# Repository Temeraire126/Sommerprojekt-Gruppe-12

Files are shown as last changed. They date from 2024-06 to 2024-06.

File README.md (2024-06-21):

KeySync

Ein Softskills-Projekt der Carl von Ossietzky Universität Oldenburg.

Wir haben im Rahmen des Moduls "Softskills und Technische Kompetenzen" einen smarten Schlüsselkassten entwickelt, der die Vermietung von Räumen vereinfachen soll.

Wichtig: Dies ist ein Prototyp und sollte auf keinen Fall in seiner jetztigen Form tatsächlich verwendet werden.

Das Projekt besteht aus zwei Komponenten, einem Mainboard/Hub und einer beliebigen Anzahl an Schlüsselkästen. 
Auf dem Mainboard werden auf Anfrage Zahlencodes generiert, die dann am entsprechenden Schlüsselkasten eingegeben werden können um den Schlüssel freizugeben.

Betrieben wird das System von mehreren ESP8266 und nutzt das ESPnow protocoll zur Komunikation. Die Gehäuse wurden mit einem Lasercutter hergestellt.

Die Nutzung ist simpel genug:
  1. Ein Raum wird bei einer Person (z.B. Raumverwaltung oder Rezeption) angefordert.
  2. Durch Knopfdruck am Mainboard wird ein 4 stelliger Pin generiert und kann an die ensprechende Person weiter geleitet werden.
  3. Bei eingabe des Pins öffnet sich der Deckel und der Schlüssel kann entnommen werden
  4. Wenn der richtige Schlüssel wieder in den Kassten gelegt wird schließt sich der Deckel automatisch.

     Sowohl auf dem Mainbard, als auch auf dem Schlüsselkasten wird der Raumstatus mittels farbiger LEDs gekenzeichnet.

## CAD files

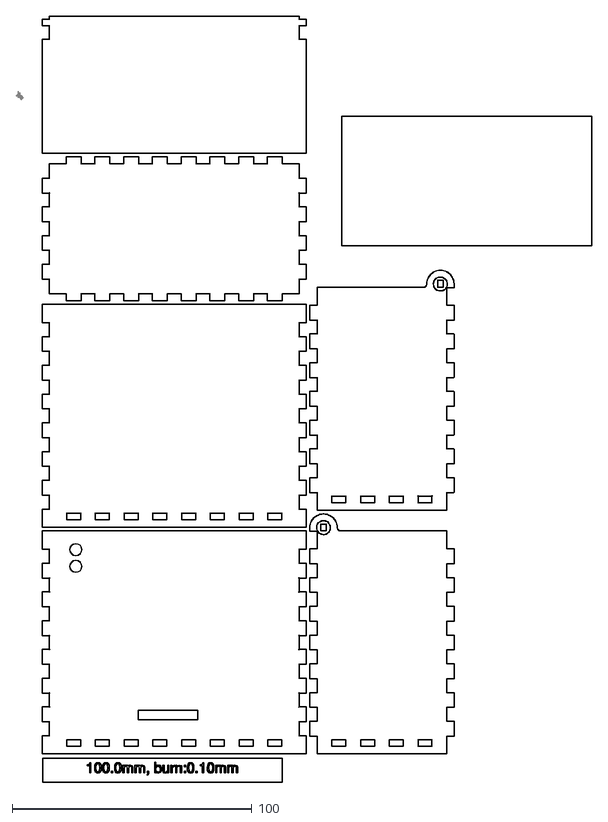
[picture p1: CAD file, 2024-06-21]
Casefiles/Tresor_box.dxf
240.1 x 319.8

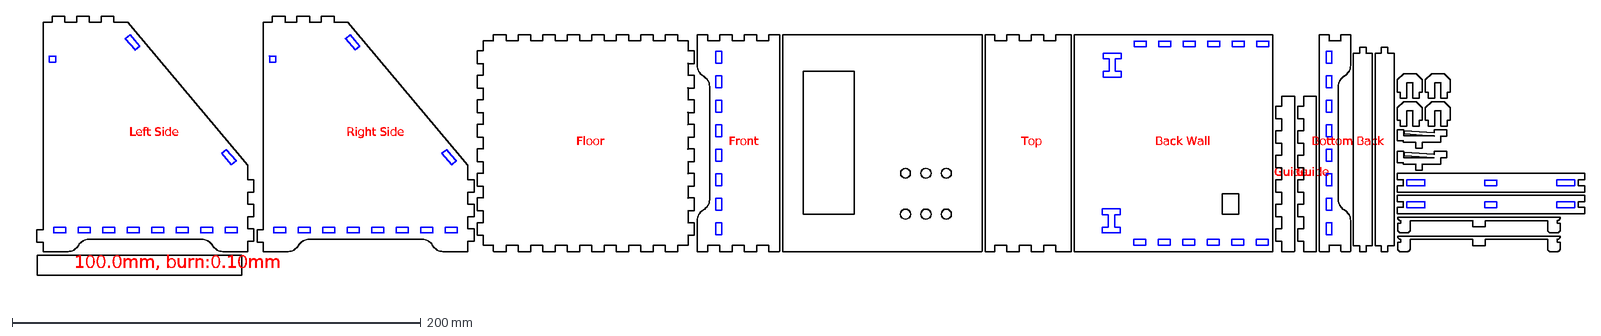
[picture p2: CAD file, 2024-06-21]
Casefiles/Hub-Case.dxf
100.0mm, burn:0.10mm
Left Side
Right Side
Floor
Front
Top
Back Wall
Guide
Bottom Back

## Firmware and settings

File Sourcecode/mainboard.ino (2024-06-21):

#include <espnow.h>
#include <ESP8266WiFi.h>
#include <String>
//Pins
#define REDLED1 D5
#define REDLED2 D8
#define GREENLED1 D4
#define GREENLED2 D7
#define BUTTON1 D6
#define BUTTON2 D3

//Display
#include <LiquidCrystal_I2C.h>       
LiquidCrystal_I2C lcd(0x27, 16, 2);  //Hier wird festgelegt um was für einen Display es sich handelt
//PINs des Displays:
//- SCL: D1   grau
//- SDA: D2   weiß

const int codeLength =4;
//für weitere Tresore die Adressse im gleichen Vormat speichern:
  //Adressen der D1Mini Keypads (passcode wird hierhin gesendet)
  uint8_t addressMini1[] = {0xFF,0xFF,0xFF,0xFF,0xFF,0xFF};//0xC8,0xC9,0xA3,0x14,0x32,0x59
  uint8_t addressMini2[] = {0xFF,0xFF,0xFF,0xFF,0xFF,0xFF};//0x60,0x01,0x94,0x10,0x09,0x3C
 //uint8_t addressMini3[] = ....

  //Adressen der NodeMCUs von denen der Status der Tresore erhalten wird (wird zur Unterscheidung der Tresore verwendet)
  uint8_t recvAddress1[] = {0xFF,0xFF,0xFF,0xFF,0xFF,0xFF};//0x4C,0x75,0x25,0x36,0xBD,0x64
  uint8_t recvAddress2[] = {0xFF,0xFF,0xFF,0xFF,0xFF,0xFF};//0x08,0x3A,0x8D,0xCF,0xAF,0x55
  //uint8_t recvAddress3[]=...

//pakate definieren und initialisieren
//sendet:
 typedef struct packageCodeStruct{
  String a;
 } packageCodeStruct;
//erhält:
 typedef struct packageResponseStruct{
  bool b;
 } packageResponseStruct;

 packageCodeStruct sendData;
//eine variable für jeden Tresor, der einen Wert zurückschickt. So wird sich der Status aller Schlüssel gemerkt.
 packageResponseStruct recvData1;
 packageResponseStruct recvData2;
//packageResponseStrct recvData3;
//...

//Sind Schlüssel in den Tresoren?
bool statusTresor1=true;
bool statusTresor2=true;
//bool statusTresor3...

bool codeIsDisplayed = false; 

//Aufruf bei Datenerhalt. Abhängig der Senderadresse wird der Inhalt in verschiedene variablen gespeichert
//Bei weiteren Tresoren muss für jeden neuen eine eigene Abfrage gemacht werden
void OnDataRecv(uint8_t * mac, uint8_t *incomingData, uint8_t len){
  if(0==memcmp(recvAddress1, mac , sizeof(mac))){
  memcpy(&recvData1, incomingData,sizeof(recvData1));
  }
  if(0==memcmp(recvAddress2, mac, sizeof(mac))){
  memcpy(&recvData2, incomingData,sizeof(recvData2));
  }
 /*
    if(0==memcmp(recvAddress3, mac, sizeof(mac))){
  memcpy(&recvData3, incomingData,sizeof(recvData3));
  }
  */
  Serial.print("received");
  updateLED();
}
// Debugginghilfe beim Versenden der Passcodes:
void onDataSent(uint8_t *mac_addr, uint8_t sendstatus){
  Serial.print("Last Packet Send Status: ");
  if(sendstatus == 0){
    Serial.println("Delivery success");
  }
  else {
    Serial.println("Delivery fail");
  }
}

void setup() {
  Serial.begin(115200);
 //Pin Modes:
      pinMode(REDLED1, OUTPUT);
      pinMode(REDLED2, OUTPUT);
      pinMode(GREENLED1, OUTPUT);
      pinMode(GREENLED2, OUTPUT);
      pinMode(BUTTON1, INPUT_PULLUP);
      pinMode(BUTTON2, INPUT_PULLUP);
   //INIT für ESPNOW
  WiFi.mode(WIFI_STA);
  if(esp_now_init() != 0){
    Serial.println("Error initilizing ESPNOW");
    return;
  }
  esp_now_set_self_role(ESP_NOW_ROLE_COMBO);
  esp_now_register_send_cb(onDataSent);
  esp_now_register_recv_cb(OnDataRecv);
  esp_now_add_peer(addressMini1, ESP_NOW_ROLE_SLAVE, 1, NULL, 0);
  esp_now_add_peer(addressMini2, ESP_NOW_ROLE_SLAVE, 2, NULL, 0);
}
//generiert einen zufälligen 4-stelligen Zahlencode
String generateCode(){
  char code[codeLength];
  int zahl;
  for (int i = 0; i< codeLength; i++){
    zahl = (rand()%10);
    code[i] = '0' + zahl;
  }
  String rtr = code;
  return rtr;
}
//stellt den Status der Tresore in den LEDs dar (grün=schlüssel ist vorhanden und kann abgeholt werden. rot= schlüssel wurde entfernt und wird verwendet)
//auch hier wäre eine Erweiterung bei neuen Tresoren notwending. Bei mehr als 2 oder 3 Tresoren wäre es sinnvoller das ganze über einen for-Schleife laufen zu lassen und die outputs vorher in einem Array zu speichern

void updateLED(){
  statusTresor1=recvData1.b;
  statusTresor2=recvData2.b;
 if (statusTresor1) {
        digitalWrite(GREENLED1, HIGH);
        digitalWrite(REDLED1, LOW); 
        Serial.println(" 1 present");
  } else {
        digitalWrite(REDLED1, HIGH);
        digitalWrite(GREENLED1, LOW);
        Serial.println(" 1 gone");
  }
  if (statusTresor2) {
        digitalWrite(GREENLED2, HIGH);
        digitalWrite(REDLED2, LOW);
        Serial.println(" 2 present");
  } else {
        digitalWrite(REDLED2, HIGH);
        digitalWrite(GREENLED2, LOW);
        Serial.println(" 2 gone");
  }
}
//Zeigt den Code auf dem LCD an
void showCode(char values[]){
for (int i = 0; i < sizeof(values); i++) {
        lcd.setCursor(0, i);
        lcd.print(values[i]);
      }
}
//Erstellt bei Knopfdruck einen Code und schickt diesen an den jeweiligen D1Mini
void loop() {
 //Tresor 1
  if(digitalRead(BUTTON1) == LOW){
    String code=generateCode();
    sendData.a=code;
    esp_now_send(addressMini1, (uint8_t *)&sendData,sizeof(sendData));
    delay(1000);
  }
 //Tresor 2
  delay(100);
  if(digitalRead(BUTTON2)== LOW){
    String code = generateCode();
    sendData.a=code; 
    esp_now_send(addressMini2, (uint8_t *)&sendData,sizeof(sendData));
    delay(1000);   
  }
 /*
 delay(100);
 if(digitalRead(BUTTON3)==LOW){
 ...
 }
 */
}

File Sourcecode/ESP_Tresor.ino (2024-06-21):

// Bibliotheken hinzufügen
#include <espnow.h>
#include <ESP8266WiFi.h>
#include <MFRC522.h>
#include <Servo.h>

//Anschlüsse definieren
#define SDA_Pin D1
#define RST_Pin D4
//mainboardadresse und paket definieren
uint8_t addressMain[] = {0xFF,0xFF,0xFF,0xFF,0xFF,0xFF}; //hier die MAC-Adresse deines Mainboards einfügen z.B.: 0x08,0x3A,0x8D,0xCF,0xAE,0x38
 typedef struct packageSend{
  bool a;
 } packageSend;
 packageSend sendData;
//LEDs
#define LED_RED D2
#define LED_GREEN D3
//Signal für korrekte Codeeingabe
#define Input_Keypad D0

//RFID-Empfänger bennen, Pins zuordnen
MFRC522 mfrc522(SDA_Pin, RST_Pin);
//PINs RFID:
//SDA  =  D1
//SCK  =  D7
//MOSI =  D6
//MISO =  D5
//IRQ  =  nicht angeschlossen
//RST  =  D4

//Variable zum Speichern ob der Schlüssel momentan im Tresor ist.
boolean keyThere = true;

//Benennung des Servo
Servo myservo;
int pos = 0;

//Aufruf bei Senden von Daten, Inhalt nur für Debug-swecke:
void onDataSent(uint8_t *mac_addr, uint8_t sendstatus){
      Serial.print("Last Packet Send Status: ");
  if(sendstatus == 0){
    Serial.println("Delivery success");
  }
  else {
    Serial.println("Delivery fail");
  }
}


void setup() {
 //INIT für ESPNOW
  WiFi.mode(WIFI_STA);
  if(esp_now_init() != 0){
    Serial.println("Error initilizing ESPNOW");
    return;
  }
  esp_now_set_self_role(ESP_NOW_ROLE_CONTROLLER);
  esp_now_register_send_cb(onDataSent);
  esp_now_add_peer(addressMain, ESP_NOW_ROLE_COMBO, 3, NULL, 0);
//Servo festlegen
 myservo.attach(D8);

  Serial.begin(115200);
  SPI.begin();

  //Initialsierung des RFID-Empfängers
  mfrc522.PCD_Init();
  
  pinMode(LED_RED, OUTPUT);
  pinMode(LED_GREEN, OUTPUT);
}
//
void loop() {
  delay(10);
  //Schlüssel ist momentan da.
  if(keyThere){
    delay(10);
   //Korrekter Code wurde eingegeben.
    if(digitalRead(Input_Keypad)==LOW){
      digitalWrite(LED_GREEN,HIGH);
      digitalWrite(LED_RED,LOW);
      openSesame();
     //Solange der chlüssel noch da ist warten bis er entfernt wurde.
      while(checkKey()){
        delay(10);
      }
        keyThere=false;
        sendData.a=keyThere;
        esp_now_send(addressMain, (uint8_t *)&sendData,sizeof(sendData));
        digitalWrite(LED_GREEN,LOW);
    
    }
   //Schlüssel ist momentan nicht da.
  } else{
   //Wurde der Schlüssel zurückgelegt?
    if(checkKey()){
      digitalWrite(LED_GREEN,HIGH);
      delay(2000);
      closeSesame();
      keyThere=true;
      sendData.a=keyThere;
      esp_now_send(addressMain, (uint8_t *)&sendData,sizeof(sendData));

      delay(10);
     //wenn der Schlüssel beim Schließen des Tresors entfernt wurde
      if(!checkKey()){
        digitalWrite(LED_GREEN,LOW);
        openSesame();
        keyThere=false;
        sendData.a=keyThere;
        esp_now_send(addressMain, (uint8_t *)&sendData,sizeof(sendData));
        delay(10);
      }
      digitalWrite(LED_GREEN,LOW);
      digitalWrite(LED_RED,HIGH);
   
    }
  }
}

//gibt bei Korrektem Wert im RFID-Chip TRUE zurück, wenn der Wert falsch oder kein Chip erkannt wird, kommt FALSE zurück
boolean checkKey() {
  int i=0;
  int limit = 100;
String WertDEZ;
while(i<limit){
  i++;
if(mfrc522.PICC_IsNewCardPresent() && mfrc522.PICC_ReadCardSerial() ){
  Serial.println("Karte entdeckt!");

  //Dezimal-Wert in Strings schreiben
  for (byte i = 0; i < mfrc522.uid.size; i++)  //über jedes Byte der UID der Karte
  {
    //String zusammenbauen
    WertDEZ = WertDEZ + String(mfrc522.uid.uidByte[i], DEC) + " ";
  }

  //trim() -> Leerzeichen am Ende des Strings entfernen
  WertDEZ.trim();

  //Kennung dezimal anzeigen
  Serial.println("Dezimalwert: " + WertDEZ);

//Hier den Wert deines RFID-Tacks einfügen:
  return (WertDEZ == "XXXXXXX" );
}
}
return false;
}

//öffnet die Tür des Tresors:
void openSesame() {
  Serial.println("open");
  for (pos = 0; pos <= 180; pos += 1) {  //goes from 0 degrees to 180 degrees in steps of 1 degree
    myservo.write(pos);                  //tell servo to go to position in variable 'pos'
    delay(15);                           //waits 15ms for the servo to reach the position
  }
  delay(1000);
}
//schließt die Tür des Tresors:
void closeSesame() {
  Serial.println("close");
  for (pos = 180; pos >= 0; pos -= 1) {  // goes from 180 degrees to 0 degrees
    myservo.write(pos);                  // tell servo to go to position in variable 'pos'
    delay(15);                           // waits 15 ms for the servo to reach the position
  }
}

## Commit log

2024-06-05 Warum ist der Servo bei CLK angeschlossen???
2024-06-07 Add files via upload
    Rahmen für die Kommunikation des mainboards zu den Tresoren
2024-06-10 Update and rename RFID_TestVersuch.ino to RFIDUndServo.ino
    Code für RFID und Servo funktioniert
2024-06-10 Rename RFID to RFID und Servo
2024-06-10 now sends digital signal when correct code is input
    [D1miniTest.ino]
